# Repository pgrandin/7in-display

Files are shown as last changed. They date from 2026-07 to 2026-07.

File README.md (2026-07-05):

# MPI7002 7" HDMI Touch Display — CAD models & Linux notes

> 🤖 **An LLM experiment.** Everything in this repository — the CAD
> models, the printable enclosure, the renders, and these docs — was
> generated with an LLM (Claude, via Claude Code), starting from nothing
> but a part reference and the manufacturer's published documentation.

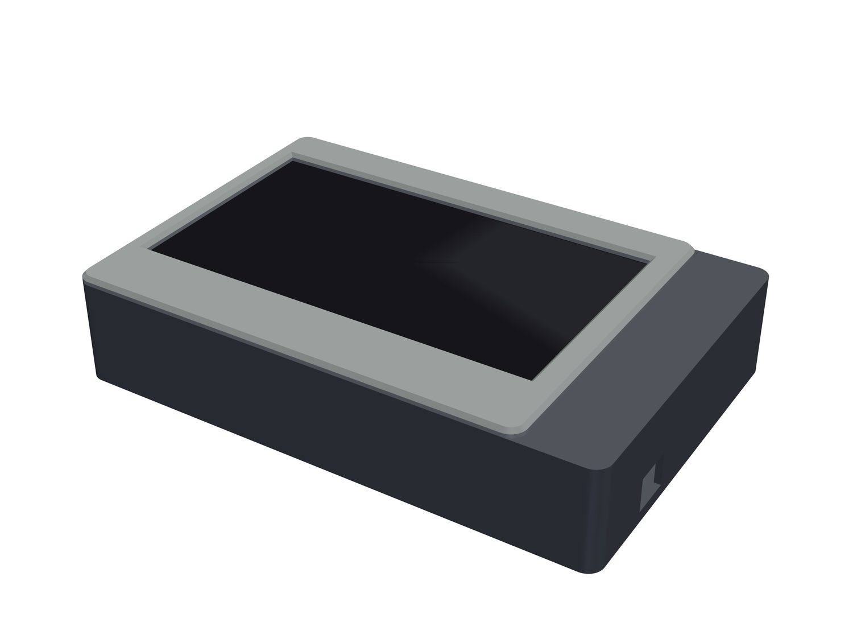
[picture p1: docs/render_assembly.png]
Assembled enclosure


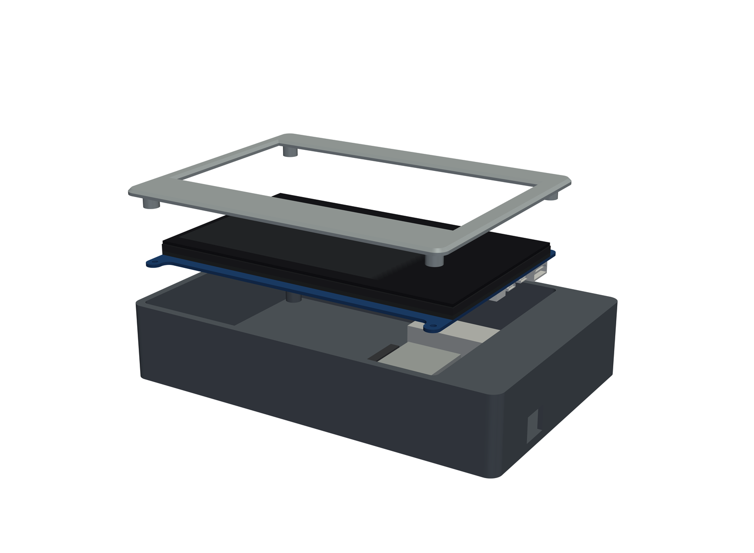
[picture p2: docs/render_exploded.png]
Exploded view: front panel, display module, back case with Raspberry Pi 5


CAD models, a 3D-printable enclosure, and Linux setup notes for the
LCDwiki **MPI7002** / *7inch HDMI Display-C* — a 7" 1024x600 IPS panel
with five-point capacitive touch, sold under many brand names (Hosyond,
OSOYOO, and others). If your panel's EDID reports `MPI7002` and the touch
controller enumerates as USB `0484:5750`, this is your display.

Full specifications and datasheets:
[lcdwiki.com/7inch_HDMI_Display-C](https://www.lcdwiki.com/7inch_HDMI_Display-C)

## Why this repo

This is an experiment in building accurate, printable CAD designs from
nothing but a part reference: no calipers, no vendor STEP files — just
the manufacturer's published outline drawing and product images, read
carefully (including reconciling contradictions between drawing views),
turned into parametric CadQuery models, and validated with programmatic
dimension and collision checks.

## CAD Models

Everything lives in `cad/` and regenerates from the scripts in `scripts/`:

- `cad/MPI7002.step` / `.stp` - display module (PCB with eared outline,
  screen stack, HDMI / micro-USB / switch connectors) for CAD assemblies
- `cad/MPI7002.3mf` - mesh export of the display model (reference only)
- `cad/MPI7002_front_panel.step` / `.stp` / `.3mf` - printable front
  bezel; the display screws to it through its four mounting-ear holes.
  The 3MF is print-oriented — slice as-is, no supports.
- `cad/MPI7002_case_back.step` / `.stp` / `.3mf` - printable back case
  with an internal Raspberry Pi 5 bay and cable compartment; four M3 x 35
  screws clamp case, display, and panel. The 3MF is print-oriented.
- `cad/MPI7002_panel_assembly.step` - display + panel reference assembly
- `cad/MPI7002_case_assembly.step` - display + panel + case + Pi 5
  reference assembly
- `cad/*_github_preview.stl` - open these on GitHub for the built-in 3D
  viewer
- `cad/README.md` - dimensions, coordinate system, accuracy notes, screw
  sizes, and print settings

Dimensions come from the official outline drawing
([MPI7002_Size.pdf](https://www.lcdwiki.com/res/MPI7002/MPI7002_Size.pdf));
connector body sizes are standard receptacle dimensions. Caliper-check the
mounting-hole spacing (expected `156.90 x 114.96 mm`) before drilling or
committing a print.

## Display Setup (Linux / X11)

The panel is plug-and-play over HDMI (native mode `1024x600 @ 60 Hz`) and
shows up like any monitor. If it is detected but not enabled, turn it on
with XRandR — find its output name with `xrandr --query`, then:

```bash
xrandr --output <OUTPUT> --mode 1024x600 --pos <X>x<Y>
```

## Touch Mapping

Touch arrives as a USB HID multitouch device named `QDTECH MPI700
MPI7002` (`0484:5750`) and works out of the box on a single-monitor
setup. On multi-monitor setups, map the touch area to the panel's output:

```bash
xinput list                        # find the device id
xinput map-to-output <ID> <OUTPUT>
```

The id can change after reboot or replug, so look it up rather than
hardcoding it.

## Brightness

The panel exposes no kernel backlight device and no DDC; the hardware
control is the physical backlight switch next to the ports. In software
you can scale the rendered image intensity per-output:

```bash
xrandr --output <OUTPUT> --brightness 0.7    # 0.05..1.0 useful range
```

The `7in-brightness` script wraps this; point it at your output with the
`DISPLAY_OUTPUT` environment variable (defaults to `DP-4`):

```bash
export DISPLAY_OUTPUT=DP-4   # your panel's XRandR output name
./7in-brightness get
./7in-brightness set 0.70
./7in-brightness up
./7in-brightness down
./7in-brightness loop        # sweep 0% -> 100% in 10% steps
```

Values below ~0.05 effectively blank the output; `1.00` is normal.

## Hardware Identification

- EDID display name and serial text: `MPI7002`
- Touch controller: `QDTECH MPI700 MPI7002`, USB `0484:5750` (HID
  multitouch, STM32-based)
- EDID-reported physical size is bogus (`255mm x 255mm`); the real active
  area is `154.21 x 85.92 mm`

Raw detection logs from a first bring-up (XRandR, EDID, DRM, USB, touch
calibration) are in [OBSERVED_STATE.md](OBSERVED_STATE.md).

## Regenerating the CAD Models

```bash
uv venv .venv-cad --python 3.11
uv pip install --python .venv-cad/bin/python -r requirements-cad.txt
.venv-cad/bin/python scripts/generate_step.py    # display model
.venv-cad/bin/python scripts/generate_panel.py   # front panel
.venv-cad/bin/python scripts/generate_case.py    # back case + assemblies
.venv-cad/bin/python scripts/render_previews.py  # README render images
```

See `cad/README.md` for validation steps and expected outputs.

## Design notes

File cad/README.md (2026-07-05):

# MPI7002 CAD Model

CAD reference model for the LCDwiki `MPI7002` / `7inch HDMI Display-C`
module (also sold rebranded, e.g. Hosyond 7" — Amazon `B09XKC53NH`; the
EDID and USB descriptors identify the same QDTECH MPI7002 board).

## Files

- `MPI7002.step` / `MPI7002.stp` - STEP B-rep assembly (same file, two
  extensions). Use this for CAD work.
- `MPI7002.3mf` - 3MF mesh export of the same geometry
- `MPI7002.scad` - editable OpenSCAD source model
- `MPI7002_github_preview.stl` - GitHub-renderable preview mesh
- `MPI7002_front_panel.step` / `.stp` / `.3mf` - 3D-printable front panel
  (bezel). The 3MF is already print-oriented (front face on the bed);
  slice as-is, no supports. The STEP is in assembly coordinates.
- `MPI7002_front_panel_github_preview.stl` - panel preview mesh
  (assembly coordinates, not print-oriented)
- `MPI7002_panel_assembly.step` - display module + panel combined, for
  CAD reference
- `MPI7002_case_back.step` / `.stp` / `.3mf` - 3D-printable back case
  that pairs with the front panel. The 3MF is already print-oriented
  (exterior back on the bed); slice as-is. The STEP is in assembly
  coordinates.
- `MPI7002_case_back_github_preview.stl` - case preview mesh
  (assembly coordinates, not print-oriented)
- `MPI7002_case_assembly.step` - display module + panel + case combined

## Front Panel

Generated by `scripts/generate_panel.py`. The display hangs behind the
panel, attached through its four mounting-ear holes:

- Plate `174.90 x 134.27 x 3.00 mm` (5 mm border around the PCB), outer
  corners R6, front edges chamfered 1.5 mm at 45 degrees.
- Window opens the LCD active area plus 1.0 mm per side
  (`156.21 x 87.92 mm`); the bezel overlaps the touch lens by at least
  2.3 mm all around, so the lens seats flat on the panel back.
- Four Ø8 bosses on the back drop down to the PCB mounting ears. Drive
  `M3 x 8` screws from behind through the ear holes into the Ø2.8 pilot
  holes (thread-forming in PLA/PETG). For heat-set inserts, change
  `PILOT_D` to 4.6 in `scripts/generate_panel.py` and regenerate.
- Boss faces sit 0.18 mm short of the nominal PCB plane so the screws
  lightly preload the glass against the panel; the module's foam tape
  layers absorb it.
- Print face-down (front face on the bed): flat plate, straight bosses,
  45-degree chamfers — no supports needed.

Regenerate with:

```bash
.venv-cad/bin/python scripts/generate_panel.py
```

## Back Case (with Raspberry Pi 5 bay)

Generated by `scripts/generate_case.py`. Completes the enclosure around
the front panel and carries a Raspberry Pi 5 with fully internal cabling:

- Exterior `202.90 x 134.27`, back at z -30.50 (overall depth with panel:
  42.38 mm). The extra width is an internal cable bay on the right; the
  front panel is unchanged and its right border rests on the bay roof.
- The display's HDMI, micro-USB, and backlight switch open into the bay
  (30 mm deep). Use right-angle or short-boot plugs; straight full-size
  HDMI plugs will not fit. No display ports are exposed outside.
- Pi 5 mounts component-side-up on four Ø6 standoffs (M2.5 pilot holes
  Ø2.05, or 3.5 for heat-set inserts; board footprint x 100..156,
  y 10..95). Its USB-C / micro-HDMI edge faces the bay for the internal
  micro-HDMI-to-HDMI and USB-A-to-micro-USB (touch) jumpers; the
  USB/Ethernet edge faces the interior and the GPIO header stays
  reachable. Opening the case is required for USB/Ethernet/SD access.
- The only external openings: a `16 x 13` cable pass-through slot in the
  bay wall (power cord, optionally Ethernet) and nine vent slots in the
  back under the Pi.
- Four Ø9 hollow pillars rise from the case floor to the PCB mounting
  ears. `M3 x 35` socket-head screws from the back seat in Ø6.5
  counterbores and thread into the front panel's bosses — four screws
  clamp case, display, and panel. (With the case, skip the panel-only
  `M3 x 8` screws.)
- Print back-face-down: walls, pillars, and standoffs rise straight up.
  The bay roof is a single ~33 mm bridge — fine with good part cooling,
  or add supports just under it.
- `MPI7002_case_assembly.step` includes an approximate Pi 5 envelope
  (board, port stacks, active-cooler and GPIO keepouts) used for the
  clearance checks; connector positions on it are approximate.

Regenerate with:

```bash
.venv-cad/bin/python scripts/generate_case.py
```

## Sources

- LCM outline drawing: https://www.lcdwiki.com/res/MPI7002/MPI7002_Size.pdf
  (V1.0, 2024-2-21) — primary source
- Product dimensions image: https://www.lcdwiki.com/res/MPI7002/MPI7002_Product_Dimensions.png
- Wiki page: https://www.lcdwiki.com/7inch_HDMI_Display-C

## Dimensions Used

- PCB: `164.90 mm` wide x `1.60 mm` thick. The main body is `106.96 mm`
  tall; four `8.00 mm` wide mounting ears at the corners extend it to
  `124.27 mm` overall (`8.655 mm` edge recess between the ears,
  `148.90 mm` between ear inner edges). All outline corners are
  `R4.00 mm`, making the ear tips semicircular.
- Total stack thickness: `8.88 mm` (PCB 1.60 + LCD back tape 2.00 +
  LCD 3.50 + CTP back tape 0.30 + CTP lens 1.48)
- Overall envelope including HDMI connector: `164.90 x 124.27 x 15.15 mm`
- Mounting holes: `4x Ø3.00 mm`, spacing `156.90 x 114.96 mm`
  (4.00 mm from side edges, 4.655 mm from top/bottom edges)
- LCD backlight: `164.90 x 100.00 mm`, top edge 9.52 below PCB top
- CTP lens OD: `164.28 x 99.17 mm`, 0.21 from right edge, 10.08 from top
- CTP visual area: `154.68 x 87.02 mm`, 6.75 from right, 13.80 from top
- LCD active area: `154.21 x 85.92 mm`, 6.99 from right, 14.35 from top

Connectors sit on the right edge (viewed from the front), mounted on the
PCB back face and extending 6.27 mm (HDMI) behind it. Vertical centers,
measured from the PCB top edge:

- HDMI type A ("Display"): `20.25 mm`
- micro-USB ("Touch", upper): `38.62 mm`
- micro-USB ("Touch", lower): `51.73 mm`
- Backlight slide switch: `62.87 mm`

## Coordinate System

- Units are millimeters.
- Origin is the lower-left PCB corner viewed from the front (screen side).
- `+X` goes right, `+Y` up, `+Z` out of the screen toward the viewer.
- `z = 0` is the PCB back face (component side). The screen stack spans
  `z = 0 .. 8.88`; connectors span `z = -6.27 .. 0`.

## Accuracy Notes

The board outline, hole pattern, screen layer footprints, stack thickness,
and connector vertical positions are taken directly from the official
outline drawing. Note on reading that drawing: the front view dimensions
the hole pattern (`156.90 x 114.96`, holes 4.00/4.66 from the edges) while
the back view dimensions the outline (`106.96` body height, `8.65` ear
recess, `148.90` between ear inner edges) — the two views describe the
same eared outline, verified against the edge profile of the product
photo. One caveat:

- **Connector body sizes are standard, not dimensioned.** Only the HDMI
  height (6.27) comes from the drawing. The HDMI type A receptacle
  (15.0 x 11.6 body, 14.1 x 4.6 D-shaped opening with contact tongue)
  and the micro-USB B receptacles (7.7 x 5.4 x 2.45 trapezoid shell,
  6.9 x 1.85 opening with tongue) are modeled from typical receptacle
  dimensions, mating faces flush with the PCB edge (the published
  product size implies no meaningful in-plane overhang); the backlight
  switch stays a plain 9.0 x 4.2 x 3.6 envelope. The detailed connector
  geometry lives in the CadQuery/STEP model only — the OpenSCAD source
  keeps simple boxes. Measure before cutting tight connector openings.

The thin `*_marker` / `*_reference` solids on the glass are alignment aids
for the active/visual areas; suppress them in CAD if they get in the way.

## Regenerate

The STEP, 3MF, and preview STL are generated with CadQuery/OpenCascade:

```bash
uv venv .venv-cad --python 3.11
uv pip install --python .venv-cad/bin/python -r requirements-cad.txt
.venv-cad/bin/python scripts/generate_step.py
```

Validate the STEP by reading it back through CadQuery:

```bash
.venv-cad/bin/python - <<'PY'
import cadquery as cq
shape = cq.importers.importStep("cad/MPI7002.step")
bb = shape.val().BoundingBox()
print(f"x={bb.xlen:.2f} y={bb.ylen:.2f} z={bb.zlen:.2f}")
print(f"zmin={bb.zmin:.2f} zmax={bb.zmax:.2f}")
print("solids=", len(shape.solids().vals()))
PY
```

Expected readback:

```text
x=164.90 y=124.27 z=15.15
zmin=-6.27 zmax=8.88
solids= 11
```

The `15.15 mm` Z extent matches the published product size
(`164.9 x 124.27 x 15.15 mm`): 8.88 stack plus the 6.27 HDMI connector
behind the PCB.

## GitHub Preview

GitHub's built-in 3D viewer renders STL files directly. It does not
currently render STEP or 3MF in the repository file view, so open
`MPI7002_github_preview.stl` on GitHub for a browser preview.

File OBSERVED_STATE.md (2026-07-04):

# Observed State

Captured on July 4, 2026 from the Linux desktop where the panel was first
tested.

## Detection Summary

The panel was detected by XRandR as `DP-4` and enabled successfully:

```text
DP-4 connected 1024x600+7280+0 (normal left inverted right x axis y axis) 255mm x 255mm
   1024x600      60.04*+
   1920x1080     60.00    50.00    59.94
   1280x1024     75.02    60.02
   1440x900      74.98    59.90
   1152x864      75.00
   1280x720      60.00    50.00    59.94
   1024x768      75.03    70.07    60.00
   832x624       74.55
   800x600       72.19    75.00    60.32    56.25
   720x576       50.00
   720x480       60.00    59.94
   640x480       75.00    72.81    60.00    59.94
   720x400       70.08
```

The active monitor layout after enabling it:

```text
Monitors: 5
 0: +*eDP-1 1920/366x1200/229+5360+0  eDP-1
 1: +DP-1 3440/800x1440/335+1920+0  DP-1
 2: +DP-2-2 1920/477x1080/268+0+0  DP-2-2
 3: +DP-4 1024/255x600/255+7280+0  DP-4
 4: +DVI-I-1-1 1920/477x1080/268+0+1080  DVI-I-1-1
```

Before enabling, `DP-4` appeared as connected but was not listed by
`xrandr --listmonitors`.

## XRandR Verbose Details

```text
Identifier: 0x46
Gamma: 1.0:1.0:1.0
Brightness: 1.0
CRTC: 3
subconnector: HDMI
link-status: Good
CONNECTOR_ID: 275
non-desktop: 0
```

Preferred/current mode:

```text
1024x600 (0xa7c) 49.000MHz -HSync +VSync *current +preferred
        h: width  1024 start 1029 end 1042 total 1312 skew    0 clock  37.35KHz
        v: height  600 start  602 end  605 total  622           clock  60.04Hz
```

EDID from `xrandr --verbose`:

```text
00ffffffffffff003609027001010101
2215010380291a78eee5b5a355499927
135054afef00714f81c0818081808180
9500950fd1c02413002041581620050d
2300ffff0000001c000000fc004d5049
373030320a2020202020000000fd0032
4c1e510e000a202020202020000000ff
004d5049373030320a2020202020014a
020321714e0607020315961112130414
051f90230907078301000065030c0010
008c0ad090204031200c405500b98821
000018011d8018711c1620582c2500b9
882100009e011d80d0721c1620102c25
80b9882100009e011d00bc52d01e20b8
285540b9882100001e023a80d072382d
40102c4580b9882100001e00000000d0
```

The EDID includes the display name `MPI7002` and serial text `MPI7002`.

## DRM State

Relevant connector statuses:

```text
/sys/class/drm/card0-DP-4/status: connected
/sys/class/drm/card0-DP-1/status: connected
/sys/class/drm/card0-DP-2/status: disconnected
/sys/class/drm/card0-DP-3/status: disconnected
/sys/class/drm/card0-DP-5/status: disconnected
/sys/class/drm/card0-DP-6/status: connected
/sys/class/drm/card0-eDP-1/status: connected
/sys/class/drm/card2-DVI-I-1/status: connected
```

Modes exposed at `/sys/class/drm/card0-DP-4/modes` started with:

```text
1024x600
1920x1080
1920x1080
1920x1080
1920x1080
1280x1024
1280x1024
1440x900
1440x900
1152x864
```

## USB and Touch

Relevant `lsusb` lines:

```text
Bus 001 Device 048: ID 2109:2211 VIA Labs, Inc. USB2.0 Hub
Bus 001 Device 049: ID 413c:b080 Dell Computer Corp. Dell DA20 Adapter
Bus 001 Device 050: ID 0484:5750 Specialix MPI7002
Bus 004 Device 013: ID 2109:0211 VIA Labs, Inc. USB3.0 Hub
Bus 006 Device 009: ID 17e9:6000 DisplayLink Subosen DL6350
```

Relevant kernel messages at connection time:

```text
usb 1-1.2: Product: Dell DA20 Adapter
usb 1-1.2: Manufacturer: Luxshare
usb 1-1.1: Product: MPI7002
usb 1-1.1: Manufacturer: QDTECH MPI700
usb 1-1.1: SerialNumber: STM32
input: QDTECH MPI700 MPI7002 as /devices/pci0000:00/0000:00:14.0/usb1/1-1/1-1.1/1-1.1:1.0/0003:0484:5750.0013/input/input42
hid-multitouch 0003:0484:5750.0013: input,hiddev100,hidraw8: USB HID v1.01 Device [QDTECH MPI700 MPI7002] on usb-0000:00:14.0-1.1/input0
```

The original dmesg output contained an odd combining character in
`QDTECH MPI700`; the normalized name is used here for readability.

XInput list entry:

```text
QDTECH MPI700 MPI7002  id=20  [slave pointer (2)]
```

Touch properties after mapping to `DP-4`:

```text
Device Enabled: 1
Coordinate Transformation Matrix:
  0.123314, 0.000000, 0.876686,
  0.000000, 0.277778, 0.000000,
  0.000000, 0.000000, 1.000000
libinput Rotation Angle: 0.000000
libinput Calibration Matrix:
  1.000000, 0.000000, 0.000000,
  0.000000, 1.000000, 0.000000,
  0.000000, 0.000000, 1.000000
Device Node: "/dev/input/event24"
Device Product ID: 1156, 22352
```

`1156, 22352` is decimal for USB ID `0484:5750`.

## Brightness Findings

No hardware backlight interface for this panel was exposed:

```text
/sys/class/backlight/intel_backlight
  actual_brightness=504
  brightness=504
  max_brightness=504
  type=raw
```

There were no `/dev/i2c-*` devices visible during setup, and `ddcutil`,
`brightnessctl`, and `light` were not installed. `xbacklight` was installed but
is not useful for targeting this HDMI-style external panel.

The working control path is:

```bash
xrandr --output DP-4 --brightness <value>
```

Tested values:

```text
1.00 -> normal
0.70 -> visibly dimmer
0.05 -> used as practical minimum for the loop's 0% step
```

The loop test successfully stepped:

```text
0% -> 0.05
10% -> 0.10
20% -> 0.20
30% -> 0.30
40% -> 0.40
50% -> 0.50
60% -> 0.60
70% -> 0.70
80% -> 0.80
90% -> 0.90
100% -> 1.00
```

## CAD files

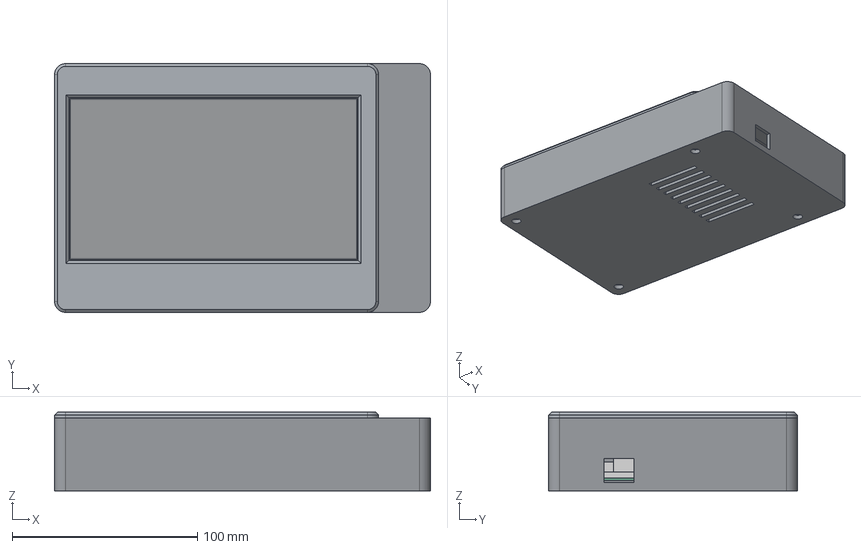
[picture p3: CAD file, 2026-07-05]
cad/MPI7002_case_assembly.step
202.9 x 134.3 x 42.4 mm
pcb_164p90x124p27x1p60
lcd_back_tape_2p00
lcd_backlight_164p90x100p00x3p50
ctp_back_tape_0p30
capacitive_touch_lens_164p28x99p17x1p48
lcd_active_area_154p21x85p92_marker
ctp_visual_area_154p68x87p02_reference
hdmi_a_receptacle
micro_usb_touch_upper
micro_usb_touch_lower
backlight_switch
front_panel
case_back
pi5_board_85x56_approx
pi5_usb_eth_stack_approx
pi5_usbc_hdmi_row_approx
pi5_soc_cooler_approx
pi5_gpio_header_approx

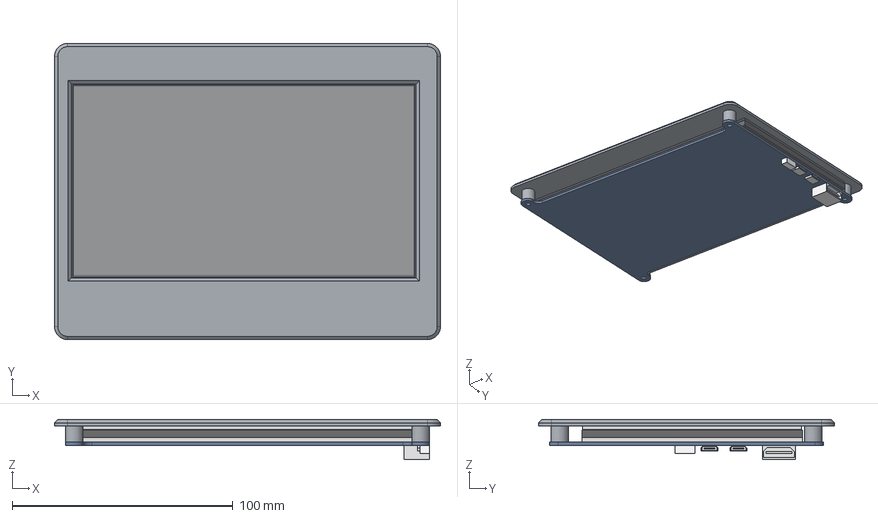
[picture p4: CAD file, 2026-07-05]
cad/MPI7002_panel_assembly.step
174.9 x 134.3 x 18.1 mm
pcb_164p90x124p27x1p60
lcd_back_tape_2p00
lcd_backlight_164p90x100p00x3p50
ctp_back_tape_0p30
capacitive_touch_lens_164p28x99p17x1p48
lcd_active_area_154p21x85p92_marker
ctp_visual_area_154p68x87p02_reference
hdmi_a_receptacle
micro_usb_touch_upper
micro_usb_touch_lower
backlight_switch
front_panel

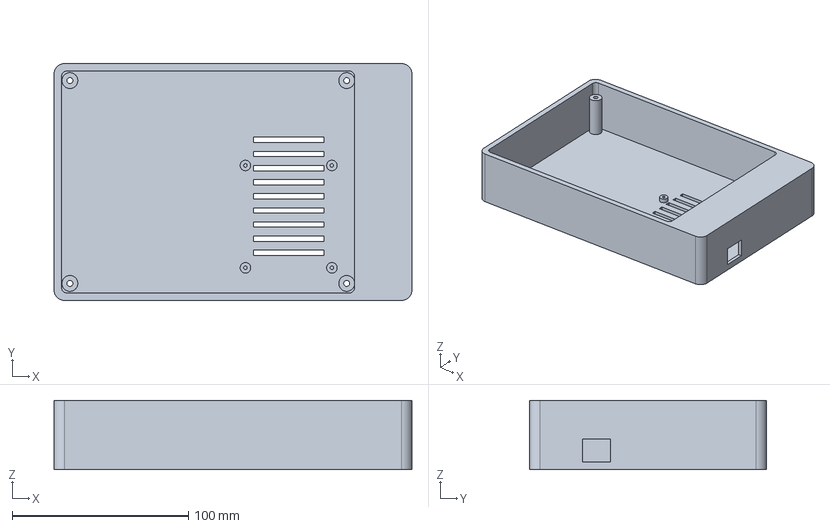
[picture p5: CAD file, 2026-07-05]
cad/MPI7002_case_back.step
202.9 x 134.3 x 39.4 mm

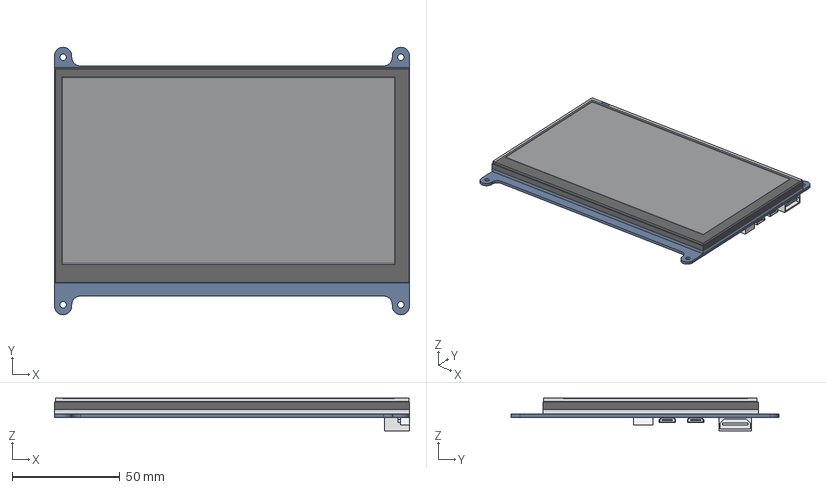
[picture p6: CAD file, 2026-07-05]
cad/MPI7002.step
164.9 x 124.3 x 15.2 mm
pcb_164p90x124p27x1p60
lcd_back_tape_2p00
lcd_backlight_164p90x100p00x3p50
ctp_back_tape_0p30
capacitive_touch_lens_164p28x99p17x1p48
lcd_active_area_154p21x85p92_marker
ctp_visual_area_154p68x87p02_reference
hdmi_a_receptacle
micro_usb_touch_upper
micro_usb_touch_lower
backlight_switch

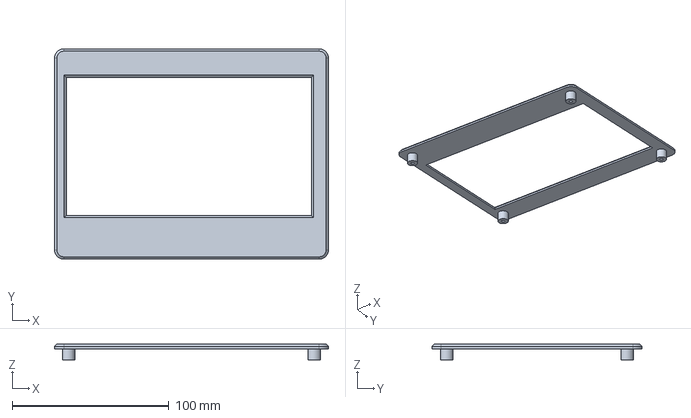
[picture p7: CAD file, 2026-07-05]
cad/MPI7002_front_panel.step
174.9 x 134.3 x 10.1 mm

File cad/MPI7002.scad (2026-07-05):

// LCDwiki MPI7002 / 7inch HDMI Display-C mechanical reference model.
// Units: millimeters.
//
// Dimensions come from the official LCM outline drawing (MPI7002_Size.pdf,
// V1.0, 2024-2-21) cross-checked against MPI7002_Product_Dimensions.png.
// Origin: lower-left PCB corner viewed from the front (screen side).
// +X right, +Y up, +Z out of the screen. z=0 is the PCB back face
// (component side); connectors extend into -Z.

$fn = 64;

// The board is not a plain rectangle: the main body is 164.90 x 106.96 and
// four 8.00-wide mounting ears at the corners extend it to 124.27 overall.
// All outline corners are R4.00, making the ear tips semicircular.
pcb_w = 164.90;
pcb_h = 124.27;
pcb_t = 1.60;
pcb_r = 4.00;
body_h = 106.96;
ear_w = 8.00;
notch_d = (pcb_h - body_h) / 2; // 8.655 recess on top and bottom edges

// 4x Ø3.00 holes centered in the ears, 156.90 x 114.96 spacing
// (4.00 / 4.655 from the edges).
hole_d = 3.00;
hole_dx = 156.90;
hole_dy = 114.96;
hole_x0 = (pcb_w - hole_dx) / 2;
hole_y0 = (pcb_h - hole_dy) / 2;

// Stack, back to front: PCB, LCD back tape, LCD, CTP back tape, CTP lens.
lcd_tape_t = 2.00;
lcd_t = 3.50;
touch_tape_t = 0.30;
touch_t = 1.48;
total_t = pcb_t + lcd_tape_t + lcd_t + touch_tape_t + touch_t; // 8.88

z_lcd_tape = pcb_t;
z_lcd = z_lcd_tape + lcd_tape_t;
z_touch_tape = z_lcd + lcd_t;
z_touch = z_touch_tape + touch_tape_t;

// Layer footprints. Horizontal offsets are from the right (connector)
// edge, vertical offsets from the top edge, per the drawing's front view.
lcd_bl_w = 164.90; lcd_bl_h = 100.00; lcd_bl_top = 9.52;
lens_w = 164.28; lens_h = 99.17; lens_right = 0.21; lens_top = 10.08;
va_w = 154.68; va_h = 87.02; va_right = 6.75; va_top = 13.80;
aa_w = 154.21; aa_h = 85.92; aa_right = 6.99; aa_top = 14.35;

// Connectors on the right edge, mounted on the PCB back face (-Z).
// Vertical centers from the drawing's dimension chain; HDMI height 6.27
// from the drawing, other body sizes are standard receptacle dimensions.
hdmi_cy = pcb_h - (4.66 + 15.59); // 104.02
usb1_cy = hdmi_cy - 18.37;        // 85.65
usb2_cy = usb1_cy - 13.11;        // 72.54
sw_cy = usb2_cy - 11.14;          // 61.40

// Mounting ear: stadium shape from the semicircular tip (R4) hulled with
// its root on the body edge. tip_y is the tip arc center.
module ear_2d(cx, tip_y, root_y) {
  hull() {
    translate([cx, tip_y]) circle(r = pcb_r);
    translate([cx - ear_w / 2, min(tip_y, root_y)])
      square([ear_w, abs(root_y - tip_y)]);
  }
}

// Board outline: recessed body plus four corner ears. The concave R4.00
// root fillets of the STEP model are omitted here (cosmetic).
module pcb_outline_2d() {
  translate([0, notch_d]) square([pcb_w, body_h]);
  for (cx = [ear_w / 2, pcb_w - ear_w / 2]) {
    ear_2d(cx, pcb_h - pcb_r, pcb_h - notch_d); // top ears
    ear_2d(cx, pcb_r, notch_d);                 // bottom ears
  }
}

module board() {
  color("#173d73")
    difference() {
      linear_extrude(height = pcb_t)
        pcb_outline_2d();

      for (x = [hole_x0, hole_x0 + hole_dx])
        for (y = [hole_y0, hole_y0 + hole_dy])
          translate([x, y, -0.5])
            cylinder(h = pcb_t + 1.0, d = hole_d);
    }
}

module screen_stack() {
  // LCD back tape layer.
  color([0.1, 0.1, 0.1, 0.35])
    translate([0, pcb_h - lcd_bl_top - lcd_bl_h, z_lcd_tape])
      cube([lcd_bl_w, lcd_bl_h, lcd_tape_t]);

  // Backlight/LCD block.
  color("#1b1b1b")
    translate([0, pcb_h - lcd_bl_top - lcd_bl_h, z_lcd])
      cube([lcd_bl_w, lcd_bl_h, lcd_t]);

  // CTP back tape.
  color([0.1, 0.1, 0.1, 0.35])
    translate([pcb_w - lens_right - lens_w, pcb_h - lens_top - lens_h, z_touch_tape])
      cube([lens_w, lens_h, touch_tape_t]);

  // Capacitive touch glass/lens.
  color([0.02, 0.02, 0.025, 0.62])
    translate([pcb_w - lens_right - lens_w, pcb_h - lens_top - lens_h, z_touch])
      cube([lens_w, lens_h, touch_t]);

  // LCD active area marker, just under the glass surface.
  color([0.05, 0.08, 0.10, 0.92])
    translate([pcb_w - aa_right - aa_w, pcb_h - aa_top - aa_h, total_t - 0.04])
      cube([aa_w, aa_h, 0.03]);

  // CTP visual-area outline.
  color([0.9, 0.9, 0.9, 0.35])
    translate([pcb_w - va_right - va_w, pcb_h - va_top - va_h, total_t - 0.01])
      difference() {
        cube([va_w, va_h, 0.01]);
        translate([(va_w - aa_w) / 2, (va_h - aa_h) / 2, -0.01])
          cube([aa_w, aa_h, 0.03]);
      }
}

// Connector body flush with the right PCB edge, on the back face.
module edge_connector(cy, w, depth, t) {
  translate([pcb_w - depth, cy - w / 2, -t])
    cube([depth, w, t]);
}

module connectors() {
  // HDMI type A receptacle ("Display").
  color("#c8c8c8") edge_connector(hdmi_cy, 15.00, 11.60, 6.27);

  // Two micro-USB receptacles (silkscreened "Touch").
  color("#d0d0d0") edge_connector(usb1_cy, 7.70, 5.40, 2.45);
  color("#d0d0d0") edge_connector(usb2_cy, 7.70, 5.40, 2.45);

  // Backlight slide switch (ON/OFF).
  color("#eeeeee") edge_connector(sw_cy, 9.00, 4.20, 3.60);
}

module labels() {
  color("white")
    translate([112, 37, -0.05])
      rotate([180, 0, 0])
        linear_extrude(height = 0.05)
          text("MPI7002", size = 7, halign = "left", valign = "center");
}

module mpi7002() {
  board();
  screen_stack();
  connectors();
  labels();
}

mpi7002();

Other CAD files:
cad/MPI7002_github_preview.stl
cad/MPI7002_front_panel_github_preview.stl
cad/MPI7002_case_back_github_preview.stl
cad/MPI7002.3mf
cad/MPI7002_case_back.3mf
cad/MPI7002_front_panel.3mf

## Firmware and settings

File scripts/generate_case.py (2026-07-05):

#!/usr/bin/env python3
"""Generate a 3D-printable back case for the MPI7002 display + Raspberry Pi 5.

Pairs with the front panel from scripts/generate_panel.py. The enclosure
holds the display against the panel and carries a Raspberry Pi 5 mounted
on the case back, with fully internal cabling:

- The display's HDMI / micro-USB / backlight switch open into an internal
  cable bay on the right side (30 mm deep); use right-angle or short-boot
  plugs there. No display ports are exposed.
- The Pi 5 mounts component-side-up on four standoffs, its USB-C /
  micro-HDMI edge facing the cable bay. Micro-HDMI-to-HDMI and USB-A-to-
  micro-USB (touch) cables run inside the case.
- The Pi's USB/Ethernet edge faces the case interior (accessible with the
  case opened); the only external opening is a cable pass-through slot in
  the bay wall (power cord, optionally Ethernet) plus vent slots in the
  back under the Pi.
- Four hollow pillars rise from the case floor to the PCB mounting ears.
  M3 x 35 socket-head screws driven from the back go through the pillars
  and ear holes into the front panel bosses, clamping case, display, and
  panel with the same four screws.

Same coordinate system as the display model. Print back-face-down: walls,
pillars, and standoffs rise straight up; the bay roof is a single 33 mm
bridge (prints fine with cooling, or enable supports for it).
"""

from __future__ import annotations

import sys
from pathlib import Path

import cadquery as cq

sys.path.insert(0, str(Path(__file__).resolve().parent))
import generate_step as disp
import generate_panel as panel


OUT_STEP = Path("cad/MPI7002_case_back.step")
OUT_STP = Path("cad/MPI7002_case_back.stp")
OUT_3MF = Path("cad/MPI7002_case_back.3mf")
OUT_GITHUB_STL = Path("cad/MPI7002_case_back_github_preview.stl")
OUT_ASSY_STEP = Path("cad/MPI7002_case_assembly.step")

FIT_CLEAR = 0.75          # cavity clearance around the PCB, per side
WALL_T = 2.5              # bay right wall thickness
BACK_T = 2.5              # back wall thickness
ROOF_T = 2.5              # bay roof thickness

# Depth budget: Pi standoff 3.0 + board 1.4 + USB/Ethernet stack ~16 +
# clearance to the display's back-side components.
Z_TOP = disp.TOTAL_T                          # 8.88, meets the panel
Z_CAVITY = -28.0                              # interior floor
Z_BACK = Z_CAVITY - BACK_T                    # -30.5 exterior back

# Cable bay on the right: display connectors open into it.
BAY_W = 30.0                                  # interior depth for plugs
BAY_X0 = disp.PCB_W + 0.5                     # 165.4, roof/bay inner edge
BAY_X1 = BAY_X0 + BAY_W                       # 195.4
Z_BAY_TOP = Z_TOP - ROOF_T                    # 6.38, bay ceiling

EXT_X0 = -panel.PANEL_MARGIN
EXT_Y0 = -panel.PANEL_MARGIN
EXT_X1 = BAY_X1 + WALL_T                      # 197.9
EXT_Y1 = disp.PCB_H + panel.PANEL_MARGIN
EXT_R = panel.PANEL_R

PILLAR_D = 9.0
SCREW_CLEAR_D = 3.4       # M3 clearance through pillar and back wall
CBORE_D = 6.5             # M3 socket head counterbore
CBORE_DEPTH = 3.0

# --- Raspberry Pi 5 ---
# Board 85 x 56, mounting holes 58 x 49 at 3.5 from the edges. Placed with
# the long axis vertical: USB-C / 2x micro-HDMI long edge faces the cable
# bay (+X), 40-pin GPIO long edge faces the interior (-X), USB/Ethernet
# short edge faces up (+Y), microSD short edge faces down (-Y). The board
# stops short of the bottom-right case pillar.
PI_W, PI_L = 56.0, 85.0
PI_X1 = 156.0                                 # clears the pillar at x 156.4
PI_X0 = PI_X1 - PI_W                          # 100.0
PI_Y0 = 10.0
PI_Y1 = PI_Y0 + PI_L                          # 95.0
PI_HOLE_OFF = 3.5
PI_HOLE_DX, PI_HOLE_DY = 49.0, 58.0
PI_HOLES = [
    (PI_X0 + PI_HOLE_OFF + dx, PI_Y0 + PI_HOLE_OFF + dy)
    for dx in (0.0, PI_HOLE_DX)
    for dy in (0.0, PI_HOLE_DY)
]
STANDOFF_D = 6.0
STANDOFF_H = 3.0
PI_PILOT_D = 2.05         # M2.5 thread-forming; 3.5 + heat-set insert
PI_PILOT_DEPTH = 5.0
PI_BOARD_T = 1.4
Z_PI_BOT = Z_CAVITY + STANDOFF_H              # -25.0
Z_PI_TOP = Z_PI_BOT + PI_BOARD_T              # -23.6

# Cable pass-through slot in the bay's right wall (power cord etc.).
SLOT_Y0, SLOT_Y1 = 25.0, 41.0
SLOT_Z0, SLOT_Z1 = -26.0, -13.0

# Vent slots in the back wall under the Pi.
VENT_X0, VENT_LEN, VENT_W = 108.0, 40.0, 3.0
VENT_YS = [22.0 + 8.0 * i for i in range(9)]


def box(x, y, z, w, h, d) -> cq.Workplane:
    return cq.Workplane("XY").box(w, h, d, centered=False).translate((x, y, z))


def build_case() -> cq.Workplane:
    shell = (
        cq.Workplane("XY")
        .box(EXT_X1 - EXT_X0, EXT_Y1 - EXT_Y0, Z_TOP - Z_BACK, centered=False)
        .translate((EXT_X0, EXT_Y0, Z_BACK))
        .edges("|Z")
        .fillet(EXT_R)
    )

    # Main cavity: open toward the front, closed by the front panel.
    main = box(
        -FIT_CLEAR,
        -FIT_CLEAR,
        Z_CAVITY,
        BAY_X0 + FIT_CLEAR,
        disp.PCB_H + 2 * FIT_CLEAR,
        (Z_TOP - Z_CAVITY) + 1.0,
    ).edges("|Z").fillet(3.0)
    shell = shell.cut(main)

    # Cable bay: same floor, closed on the front by an integral roof that
    # also supports the front panel's right border.
    bay = box(
        BAY_X0 - 1.0,
        -FIT_CLEAR,
        Z_CAVITY,
        (BAY_X1 - BAY_X0) + 1.0,
        disp.PCB_H + 2 * FIT_CLEAR,
        Z_BAY_TOP - Z_CAVITY,
    ).edges("|Z").fillet(3.0)
    shell = shell.cut(bay)

    # Cable pass-through in the bay's right wall.
    shell = shell.cut(
        box(BAY_X1 - 1.0, SLOT_Y0, SLOT_Z0, WALL_T + 3.0, SLOT_Y1 - SLOT_Y0, SLOT_Z1 - SLOT_Z0)
    )

    # Vent slots through the back wall, under the Pi.
    for y in VENT_YS:
        shell = shell.cut(
            box(VENT_X0, y - VENT_W / 2, Z_BACK - 1.0, VENT_LEN, VENT_W, BACK_T + 2.0)
        )

    # Display clamping pillars (M3 x 35 from the back into the panel bosses).
    for x, y in panel.HOLES:
        pillar = (
            cq.Workplane("XY")
            .circle(PILLAR_D / 2)
            .extrude(0.0 - Z_CAVITY)
            .translate((x, y, Z_CAVITY))
        )
        shell = shell.union(pillar)
        shell = shell.cut(
            cq.Workplane("XY")
            .circle(SCREW_CLEAR_D / 2)
            .extrude(0.0 - Z_BACK + 1.0)
            .translate((x, y, Z_BACK - 0.5))
        )
        shell = shell.cut(
            cq.Workplane("XY")
            .circle(CBORE_D / 2)
            .extrude(CBORE_DEPTH + 0.5)
            .translate((x, y, Z_BACK - 0.5))
        )

    # Pi standoffs with M2.5 pilot holes.
    for x, y in PI_HOLES:
        standoff = (
            cq.Workplane("XY")
            .circle(STANDOFF_D / 2)
            .extrude(STANDOFF_H)
            .translate((x, y, Z_CAVITY))
        )
        shell = shell.union(standoff)
        shell = shell.cut(
            cq.Workplane("XY")
            .circle(PI_PILOT_D / 2)
            .extrude(PI_PILOT_DEPTH)
            .translate((x, y, Z_CAVITY + STANDOFF_H - PI_PILOT_DEPTH))
        )

    return shell


def build_pi_mock() -> cq.Assembly:
    """Approximate Raspberry Pi 5 envelope for clearance checks."""
    assy = cq.Assembly(name="raspberry_pi_5_approx")
    board = (
        cq.Workplane("XY")
        .box(PI_W, PI_L, PI_BOARD_T, centered=False)
        .edges("|Z")
        .fillet(3.0)
        .translate((PI_X0, PI_Y0, Z_PI_BOT))
    )
    holes = cq.Workplane("XY")
    for x, y in PI_HOLES:
        board = board.cut(
            cq.Workplane("XY")
            .circle(2.7 / 2)
            .extrude(PI_BOARD_T + 1.0)
            .translate((x, y, Z_PI_BOT - 0.5))
        )
    assy.add(board, name="pi5_board_85x56_approx", color=cq.Color(0.0, 0.35, 0.2, 1.0))
    blocks = [
        # USB/Ethernet stacks on the +Y edge (ports overhang ~2 mm).
        ("pi5_usb_eth_stack_approx", PI_X0 + 5.0, PI_Y1 - 17.5, Z_PI_TOP, 46.0, 19.5, 16.0),
        # USB-C + 2x micro-HDMI along the bay-facing edge (overhang ~1 mm).
        ("pi5_usbc_hdmi_row_approx", PI_X1 - 7.5, PI_Y0 + 5.0, Z_PI_TOP, 8.5, 50.0, 3.3),
        # SoC + official active cooler envelope.
        ("pi5_soc_cooler_approx", PI_X0 + 10.0, PI_Y0 + 20.0, Z_PI_TOP, 30.0, 40.0, 11.0),
        # 40-pin GPIO header along the -X edge.
        ("pi5_gpio_header_approx", PI_X0 + 1.0, PI_Y0 + 7.0, Z_PI_TOP, 5.0, 51.0, 8.5),
    ]
    for name, x, y, z, w, h, d in blocks:
        assy.add(box(x, y, z, w, h, d), name=name, color=cq.Color(0.6, 0.6, 0.6, 1.0))
    return assy


def main() -> None:
    OUT_STEP.parent.mkdir(parents=True, exist_ok=True)
    case = build_case()

    case_assy = cq.Assembly(name="MPI7002_case_back")
    case_assy.add(case, name="case_back", color=cq.Color(0.25, 0.27, 0.30, 1.0))
    case_assy.export(str(OUT_STEP), exportType="STEP")
    OUT_STP.write_bytes(OUT_STEP.read_bytes())

    # The 3MF is print-oriented: exterior back down on the bed (z=0),
    # walls and pillars up. The STEP stays in assembly coordinates.
    printable = case.translate((0, 0, -Z_BACK))
    cq.exporters.export(printable.val(), str(OUT_3MF), tolerance=0.05, angularTolerance=0.1)

    cq.exporters.export(case.val(), str(OUT_GITHUB_STL), tolerance=0.05, angularTolerance=0.1)

    # Full assembly: display + front panel + case + Pi 5 reference model.
    assy = disp.build()
    assy.add(panel.build_panel(), name="front_panel", color=cq.Color(0.35, 0.38, 0.42, 0.9))
    assy.add(case, name="case_back", color=cq.Color(0.25, 0.27, 0.30, 0.9))
    assy.add(build_pi_mock(), name="raspberry_pi_5_approx")
    assy.export(str(OUT_ASSY_STEP), exportType="STEP")

    for p in (OUT_STEP, OUT_STP, OUT_3MF, OUT_GITHUB_STL, OUT_ASSY_STEP):
        print(p)


if __name__ == "__main__":
    main()

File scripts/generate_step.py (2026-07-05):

#!/usr/bin/env python3
"""Generate STEP and 3MF CAD models for the LCDwiki MPI7002 display module.

All dimensions come from the official LCM outline drawing
(MPI7002_Size.pdf, V1.0, 2024-2-21) cross-checked against
MPI7002_Product_Dimensions.png. See cad/README.md for the source
discrepancies and how they were resolved.

Coordinate system: origin at the lower-left PCB corner viewed from the
front (screen side). +X right, +Y up, +Z out of the screen. z=0 is the
PCB back face (component side); connectors extend into -Z.
"""

from __future__ import annotations

from pathlib import Path

import cadquery as cq


OUT_STEP = Path("cad/MPI7002.step")
OUT_STP = Path("cad/MPI7002.stp")
OUT_3MF = Path("cad/MPI7002.3mf")
OUT_GITHUB_STL = Path("cad/MPI7002_github_preview.stl")

# --- PCB ---
# The board is not a plain rectangle: the main body is 164.90 x 106.96 and
# four 8.00-wide mounting ears at the corners extend it to 124.27 overall
# (back view of the outline drawing: 106.96 body height, 8.65 ear depth,
# 148.90 between ear inner edges). All outline corners are R4.00, which
# makes the 8.00-wide ear tips semicircular.
PCB_W = 164.90
PCB_H = 124.27
PCB_T = 1.60
PCB_R = 4.00
BODY_H = 106.96
EAR_W = 8.00
NOTCH_D = (PCB_H - BODY_H) / 2   # 8.655 recess on top and bottom edges
NOTCH_W = PCB_W - 2 * EAR_W      # 148.90 between ear inner edges

# Mounting holes: 4x Ø3.00 centered in the ears, spacing 156.90 x 114.96
# per the front view of the outline drawing and the extension lines of the
# product dimensions image (4.00 from the side edges, 4.655 from
# top/bottom edges).
HOLE_D = 3.00
HOLE_DX = 156.90
HOLE_DY = 114.96
HOLE_X0 = (PCB_W - HOLE_DX) / 2  # 4.00
HOLE_Y0 = (PCB_H - HOLE_DY) / 2  # 4.655

# --- Screen stack (z, back to front): PCB, LCD back tape, LCD, CTP back
# tape, CTP lens. Total 8.88. ---
LCD_TAPE_T = 2.00
LCD_T = 3.50
TOUCH_TAPE_T = 0.30
TOUCH_T = 1.48
TOTAL_T = PCB_T + LCD_TAPE_T + LCD_T + TOUCH_TAPE_T + TOUCH_T  # 8.88

Z_LCD_TAPE = PCB_T
Z_LCD = Z_LCD_TAPE + LCD_TAPE_T
Z_TOUCH_TAPE = Z_LCD + LCD_T
Z_TOUCH = Z_TOUCH_TAPE + TOUCH_TAPE_T

# --- Screen layer footprints. Offsets are from the drawing's front view:
# horizontal offsets dimensioned from the right (connector) edge, vertical
# offsets from the top edge. ---
LCD_BL_W, LCD_BL_H, LCD_BL_TOP = 164.90, 100.00, 9.52
LENS_W, LENS_H, LENS_RIGHT, LENS_TOP = 164.28, 99.17, 0.21, 10.08
VA_W, VA_H, VA_RIGHT, VA_TOP = 154.68, 87.02, 6.75, 13.80
AA_W, AA_H, AA_RIGHT, AA_TOP = 154.21, 85.92, 6.99, 14.35

# --- Connectors, all on the right edge (viewed from the front), mounted on
# the PCB back face and extending into -Z. Vertical centers follow the
# dimension chain on the product drawing: top edge -> hole 4.66 -> HDMI
# 15.59 -> micro-USB 18.37 -> micro-USB 13.11 -> backlight switch 11.14.
# The 6.27 HDMI height is from the drawing; the other body sizes are
# standard receptacle dimensions (not dimensioned on the drawing). ---
HDMI_CY = PCB_H - (4.66 + 15.59)          # 104.02
USB1_CY = HDMI_CY - 18.37                 # 85.65
USB2_CY = USB1_CY - 13.11                 # 72.54
SW_CY = USB2_CY - 11.14                   # 61.40

HDMI_W, HDMI_DEPTH, HDMI_T = 15.00, 11.60, 6.27
USB_W, USB_DEPTH, USB_T = 7.70, 5.40, 2.45
SW_W, SW_DEPTH, SW_T = 9.00, 4.20, 3.60


def box(x: float, y: float, z: float, w: float, h: float, d: float) -> cq.Workplane:
    return cq.Workplane("XY").box(w, h, d, centered=False).translate((x, y, z))


def edge_connector(cy: float, w: float, depth: float, t: float) -> cq.Workplane:
    """Connector body flush with the right PCB edge, on the back face."""
    return box(PCB_W - depth, cy - w / 2, -t, depth, w, t)


def d_profile(width: float, height: float, chamfer: float) -> list[tuple[float, float]]:
    """D-shaped cross-section (HDMI/micro-USB style): full-width edge away
    from the PCB, 45-degree chamfered corners on the PCB side (+v).
    Points relative to the center."""
    hw, hh = width / 2, height / 2
    return [
        (-hw, -hh),
        (hw, -hh),
        (hw, hh - chamfer),
        (hw - chamfer, hh),
        (-(hw - chamfer), hh),
        (-hw, hh - chamfer),
    ]


def yz_prism(points: list[tuple[float, float]], cy: float, cz: float, x0: float, depth: float) -> cq.Workplane:
    """Extrude a YZ cross-section along +X, centered at (cy, cz)."""
    wp = cq.Workplane("YZ").polyline([(cy + u, cz + v) for u, v in points]).close().extrude(depth)
    return wp.translate((x0, 0, 0))


def hdmi_connector() -> cq.Workplane:
    """HDMI type A receptacle: shell with D-shaped socket opening and
    contact tongue. Mating face flush with the right PCB edge, wide side
    of the D away from the PCB."""
    cz = -HDMI_T / 2
    body = box(PCB_W - HDMI_DEPTH, HDMI_CY - HDMI_W / 2, -HDMI_T, HDMI_DEPTH, HDMI_W, HDMI_T)
    cavity = yz_prism(d_profile(14.1, 4.6, 1.85), HDMI_CY, cz, PCB_W - 6.0, 6.1)
    body = body.cut(cavity)
    # Contact tongue: 11.7 x 1.0, recessed 1.0 from the mating face.
    tongue = box(PCB_W - 6.0, HDMI_CY - 11.7 / 2, cz - 0.5, 5.0, 11.7, 1.0)
    return body.union(tongue)


def micro_usb_connector(cy: float) -> cq.Workplane:
    """Micro-USB B receptacle: trapezoid shell, matching opening, and
    contact tongue. Mating face flush with the right PCB edge, wide side
    away from the PCB."""
    cz = -USB_T / 2
    body = yz_prism(d_profile(USB_W, USB_T, 1.0), cy, cz, PCB_W - USB_DEPTH, USB_DEPTH)
    cavity = yz_prism(d_profile(6.9, 1.85, 0.75), cy, cz, PCB_W - 3.0, 3.1)
    body = body.cut(cavity)
    # Contact tongue: 4.9 x 0.4, recessed 0.4 from the mating face.
    tongue = box(PCB_W - 3.0, cy - 4.9 / 2, cz - 0.2, 2.6, 4.9, 0.4)
    return body.union(tongue)
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

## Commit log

2026-07-04 Add MPI7002 CAD model
    [MPI7002.scad, MPI7002_envelope.stl]
2026-07-04 Add STEP CAD export for MPI7002
    [MPI7002.step, MPI7002.stp]
2026-07-05 Add GitHub 3D preview export
    [MPI7002.step, MPI7002.stp, MPI7002_github_preview.stl]
2026-07-05 Rebuild MPI7002 model from outline drawing; add panel and Pi 5 case
    Model corrections from the official LCM outline drawing (MPI7002_Size.pdf
    V1.0) cross-checked against the product dimensions image:
    - PCB outline is eared, not rectangular: 106.96 body with four 8.00-wide
    corner ears to 124.27 overall, R4 tips and root fillets
    - Mounting holes at 156.90 x 114.96 (was mixing front/back view values)
    - Connectors on the component side, right edge viewed from the front;
    the 6.27 HDMI dimension is stack height, not in-plane overhang
    - Screen stack at its dimensioned offsets; envelope now matches the
    published 164.9 x 124.27 x 15.15 product size
    - Add 3MF export; drop the stale envelope STL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
    [MPI7002.3mf, MPI7002.scad, MPI7002.step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]
2026-07-05 Detail connectors, print-ready 3MFs, public-facing README with renders
    - Model real receptacle geometry: HDMI type A with D-shaped socket
    opening and contact tongue, micro-USB B trapezoid shells with
    openings and tongues, oriented wide-side away from the PCB
    - Export panel and case 3MFs print-oriented (flat on the bed, z=0);
    STEP files stay in assembly coordinates
    - Rewrite README for a public audience: LLM-experiment note, assembly
    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
    [MPI7002.3mf, MPI7002.step, MPI7002.stp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]
2026-07-05 Render README previews with VTK; drop redundant rotated 3MF
    Replace the matplotlib triangle-soup renders with offscreen VTK
    rendering (z-buffer, phong shading, smooth normals with crisp feature
    edges, 8x MSAA). The manually rotated panel 3MF is obsolete now that
    the shipped 3MFs are print-oriented.
    [MPI7002_front_panel_rotated.3mf]
